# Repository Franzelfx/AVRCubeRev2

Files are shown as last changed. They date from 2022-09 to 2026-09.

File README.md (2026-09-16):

# AVR-Cube (Rev2)

**A coin-cell powered electronic dice and two-axis spirit level on an ATtiny24 — seven LEDs, one button, one accelerometer, and a bit-banged I²C bus that shares its pins with the ISP header.**

Shake it and it rolls a number; press the button and the same seven LEDs become a bubble level that follows the tilt of the board. It sleeps after a minute of stillness and wakes on the button, so a CR2032 lasts a long time. Designed as an easy, satisfying through-hole soldering kit: 25 parts, all on one side.

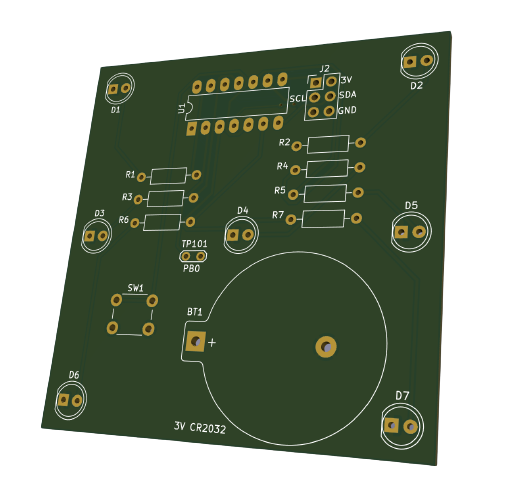
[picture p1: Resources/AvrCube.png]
AVR-Cube Rev2 board render


https://user-images.githubusercontent.com/38862049/217531555-265ecb9a-27d7-4d04-bca4-034f5620d8f7.mov

---

## Contents

- [How it works](#how-it-works)
- [Hardware](#hardware)
- [Firmware](#firmware)
- [Building and flashing](#building-and-flashing)
- [Repository layout](#repository-layout)
- [Status and known limitations](#status-and-known-limitations)
- [Author](#author)
- [License](#license)

---

## How it works

The whole device is one state machine driven by two interrupts: a 1 ms timer tick that counts idle time, and the button on `INT0`.

```mermaid
stateDiagram-v2
    [*] --> Calibrate : battery inserted / wake from sleep
    Calibrate --> SpiritLevel : all LEDs → "1" → sensor check ✓ → "2" → offset averaged → ✓
    Calibrate --> Sleep : sensor not answering (✗ shown for 60 s)

    SpiritLevel --> Dice : button
    Dice --> SpiritLevel : button

    state Dice {
        [*] --> Waiting
        Waiting --> Rolling : tilt changes by > 25°
        Rolling --> Waiting : 5 fast + 5 slowing steps, last number stays lit
    }

    SpiritLevel --> Sleep : 60 s without motion
    Dice --> Sleep : 60 s without motion
    SpiritLevel --> Sleep : button held 3 s
    Dice --> Sleep : button held 3 s
    Sleep --> Calibrate : button
```

**Calibration** runs on every wake-up: it lights all LEDs (a visual LED test), reads the accelerometer's `WHO_AM_I` register over I²C, and averages ten samples to get the resting offset on each axis. That offset is what makes the spirit level read "flat" wherever the board happens to sit when powered on — there is no absolute calibration.

**Spirit level** reads X/Y/Z acceleration, subtracts the offset, and converts the X and Y components into roll and pitch angles with `atan(axis / z_offset)`. Within ±1° of level only the centre LED is lit; otherwise the LEDs on the side that is *down* light up — a whole edge if the tilt is along one axis, a single corner if it's diagonal.

**Dice** waits until the angle changes by more than 25° between two readings (a shake or a tilt), then rolls: five numbers at 100 ms, then five more with the delay growing by 100 ms each step, so the animation visibly slows down and settles. The random generator is seeded from the millisecond counter, so the result depends on exactly when you shook it.

**Sleep** puts the accelerometer in standby, switches every I/O pin to input, and enters `SLEEP_MODE_PWR_DOWN` — a few µA. Holding the button lights the LEDs 1…6 as a countdown; at 3 s it sleeps immediately.

## Hardware

| | |
|---|---|
| MCU | Microchip **ATtiny24** (DIP-14, 2 KB flash) at 8 MHz internal RC — the ATtiny84 is a drop-in alternative with more flash |
| Sensor | NXP **MMA8653FC** 3-axis accelerometer (DFN-10), I²C address `0x1D`, ±2 g, 8-bit fast-read mode |
| Display | 7 × 5 mm LEDs in the classic dice pattern, 100 Ω series resistors |
| Input | 6 mm tactile switch on `INT0` |
| Power | CR2032 in a Keystone 106 holder, 3 V direct — no regulator |
| Programming | 2×3 ISP header; the same pins carry the sensor's I²C bus |
| Board | 2-layer, single-sided assembly, KiCad 6 sources in [PCB/](PCB/), Gerbers in [PCB/Gerber/Rev26.09.22/](PCB/Gerber/Rev26.09.22/) |

### LED layout and pin map

```
        D1 ●     ● D2            D1  PA0     D5  PA5 (also MISO)
                                 D2  PA1     D6  PA7
        D3 ●  ●  ● D5            D3  PA2     D7  PB1
              D4                 D4  PA3

        D6 ●     ● D7            SW1  PB2 / INT0   (pull-up, active low)
                                 SCL  PA4 = SCK    (bit-banged, no USI)
   1 → D4   2 → D3 D5            SDA  PA6 = MOSI
   3 → D1 D4 D7   4 → corners    TP101 PB0 (spare, pulled up)
   5 → corners + D4   6 → all but D4
```

Sharing `SCK`/`MOSI` with `SCL`/`SDA` is what keeps the part count down: no dedicated I²C header, and the sensor doesn't mind the ISP traffic because the firmware drives the bus in software and the sensor ignores anything without a valid start condition addressed to it. `D5` sits on `MISO` and flickers while programming — harmless.

### Bill of materials

| Ref | Qty | Part | Footprint |
|---|:---:|---|---|
| U1 | 1 | ATtiny24-20PU (or ATtiny84) | DIP-14 |
| U2 | 1 | MMA8653FCR1 | DFN-10 2×2 mm — the only SMD part |
| D1–D7 | 7 | LED 5 mm | THT |
| R1–R7 | 7 | 100 Ω | axial 0207 |
| C1–C3 | 3 | 100 nF | 0603 |
| C4–C5 | 2 | 1 µF | 0603 |
| SW1 | 1 | tactile switch 6 mm | THT |
| BT1 | 1 | CR2032 holder, Keystone 106 | THT |
| J2 | 1 | pin header 2×3, 2.54 mm | THT |

The schematic ([PCB/avrCubeRev2.kicad_sch](PCB/avrCubeRev2.kicad_sch)) is the authoritative BOM; datasheets for every active part are in [Documentation/](Documentation/).

## Firmware

Everything lives in [AvrCubeV2Code/src/main.cpp](AvrCubeV2Code/src/main.cpp) and [main.hpp](AvrCubeV2Code/src/main.hpp) — bare-metal AVR C++ with no Arduino API calls, built with the PlatformIO `atmelavr` toolchain. Doxygen comments on every function; the generated reference is in [Documentation/Doxygen/documentation.pdf](Documentation/Doxygen/documentation.pdf).

Things worth knowing before you change it:

- **I²C is bit-banged** (`start()`, `stop()`, `tx()`, `rx()`) at ~100 kHz using the internal pull-ups — the ATtiny24's USI is not used so the pins can double as ISP. Interrupts are disabled during each register transaction.
- **The 1 ms tick** is Timer0 in CTC mode (prescaler 64, `OCR0A = 124` at 8 MHz). It only increments `counter`; `main()` compares it against `SLEEP_THRESHOLD` and any detected motion resets it.
- **Mode switching** is done by parity of `button_pressed`: the ISR increments it and re-enters `main()`, which re-initialises the peripherals and picks the branch. Odd = dice, even = spirit level; calibration leaves it at 2, so the device starts in level mode.
- **All tunables are `#define`s** at the top of `main.hpp`: sleep timeout, shake threshold, dice animation timing, level dead-band, hold-to-sleep time.

## Building and flashing

Requirements: [PlatformIO](https://platformio.org/) (CLI or VS Code extension) and an ISP programmer — an Arduino running *ArduinoISP* works, that's what `flashCommand.txt` assumes.

```bash
cd AvrCubeV2Code
pio run -e attiny24            # or -e attiny84
```

Flash with avrdude, setting the fuses for the internal 8 MHz oscillator with `CKDIV8` cleared (`lfuse 0xE2`); the default `hfuse 0xDF` keeps `RESET` usable so the chip stays re-programmable:

```bash
avrdude -p t24 -c avrisp -b 19200 -P /dev/ttyUSB0 \
  -U flash:w:.pio/build/attiny24/firmware.hex \
  -U lfuse:w:0xe2:m -U hfuse:w:0xdf:m -U efuse:w:0xff:m
```

Insert the coin cell after programming. The board should light all seven LEDs, show `1`, then a tick mark (✓) if the accelerometer answered, show `2` while it averages the offset, and a tick again — then it's in spirit-level mode. A cross (✗) after `1` means the I²C link to the sensor is broken; check the DFN-10 solder joints.

## Repository layout

```
AvrCubeV2Code/         PlatformIO project
  src/main.cpp, main.hpp   the whole firmware
  platformio.ini           attiny24 and attiny84 environments
  flashCommand.txt         avrdude invocation with fuse settings
  Doxygen/Doxyfile         doc generator config
PCB/                   KiCad 6 project (schematic, layout, footprint table)
  Gerber/Rev26.09.22/      latest production files (also Rev09.22, Rev1.0)
Documentation/         datasheets (ATtiny24, MMA8653FC, LED) and the Doxygen PDF
Resources/             board render, demo video, KiCad battery-holder footprints
```

## Status and known limitations

The Rev2 board is built, tested and works as shown in the video. Things left open in the firmware:

- **Angle maths is an approximation.** Roll and pitch use `atan(x / z_offset)` with the *calibrated* Z as the fixed reference rather than `atan2(x, sqrt(y²+z²))`. It's accurate near level and increasingly off beyond ~45°, which is fine for a bubble level but not for measuring angles. The NXP app note AN3461 has the exact formulas; the code comment already points at it.
- **Motion detection is rough.** `motionDetected()` compares the angle *gradient* to the threshold without `abs()`, so only changes in the positive direction trigger — and `getGradient()` keeps a single static previous value shared between the roll and pitch calls, so each "gradient" is really roll-minus-pitch of consecutive reads. Shaking still trips it reliably, which is all the dice needs, but it should be two independent deltas with `abs()`.
- **Offset lives in RAM.** Calibration repeats on every wake-up rather than storing the offset in the sensor's own offset registers (`OFF_X/Y/Z`), which the MMA8653FC supports.
- **Mode switching re-enters `main()` from the ISR**, which is a stack-growing trick rather than a clean state variable. It works because the device sleeps or is power-cycled long before the stack matters, but it's the first thing to refactor.
- **Flash is tight on the ATtiny24.** Float `atan` plus `rand` fits, but there is little room left; the ATtiny84 environment exists for that reason.

## Author

Fabian Franz, 2022.

## License

Firmware, schematic and board layout: [MIT](LICENSE). Datasheets in `Documentation/` belong to their respective manufacturers.

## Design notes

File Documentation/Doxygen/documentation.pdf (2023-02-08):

## AVRCubeRev2

Generated by Doxygen 1.9.5

i

1 File Index | 1
2 File Documentation | 3

2.1 /Users/FabianFranz/Development/Projects/AVRCubeRev2/AvrCubeV2Code/src/main.hpp File Refer-

Index | 13

Generated by Doxygen

# Chapter 1

# File Index

## 1.1 File List

Here is a list of all documented files with brief descriptions:

/Users/FabianFranz/Development/Projects/AVRCubeRev2/AvrCubeV2Code/src/main.hpp

### 2 File Index

# Chapter 2

# File Documentation

## 2.1 /Users/FabianFranz/Development/Projects/AVRCubeRev2/AvrCube←-V2Code/src/main.hpp File Reference

Implementation of functionality for the "Cube Project".

#include <math.h>

#include <stdlib.h>

#include <avr/io.h>

#include <avr/sleep.h>

#include <util/delay.h>

#include <avr/interrupt.h>

Macros

- #define F_CPU 8000000
- #define __DELAY_BACKWARD_COMPATIBLE__
- #define BUTTON PB2
- #define D1 PA0
- #define D2 PA1
- #define D3 PA2
- #define D4 PA3
- #define D5 PA5
- #define D6 PA7
- #define D7 PB1
- #define SCK PA4
- #define MISO PA5
- #define MOSI PA6
- #define SCL PA4
- #define SDA PA6
- #define UNCONNECTED PB0
- #define OUTPUT 0
- #define INPUT 1
- #define ENABLE true
- #define DISABLE false

### 4 File Documentation

- #define ON true
- #define OFF false
- #define SLEEP_THRESHOLD 60000
- #define ACCELERATION_THRESHOLD 100
- #define DICE_STEPS_FIRST_ROUND 5
- #define DICE_STEPS_SECOND_ROUND 5
- #define DICE_TIME_STEPS 100
- #define DICE_TIME_STEPS_INCREASE 10
- #define ANGLETHRESHOLD 5
- #define CALIBRATION_STEP_DELAY 500
- #define OFFSET_CALIBRATION_STEPS 10
- #define OFFSET_CALIBRATION_STEP_DELAY 10
- #define FORCE_SLEEP_STEPTIME 500
- #define FORCE_SLEEP_TIME 6 ∗ FORCE_SLEEP_STEPTIME
- #define I2C_DELAY 10
- #define SDA_ON (PORTA |= (1 << SDA))
- #define SDA_OFF (PORTA &= ∼(1 << SDA))
- #define SCL_READ (PINA & (1 << SCL))
- #define SDA_READ (PINA & (1 << SDA))
- #define MMA8653FC_ADD 0x1D
- #define MMA8653FC_ADDR_READ 0x3B
- #define MMA8653FC_ADDR_WRITE 0x3A
- #define MMA8653FC_WHO_AM_I 0x0D
- #define MMA8653FC_XYZ_DATA_CFG 0x0E
- #define MMA8653FC_CTRL_REG1 0x2A
- #define MMA8653FC_SYSMOD 0x0B
- #define MMA8653FC_OUT_X_MSB 0x01
- #define MMA8653FC_OUT_X_LSB 0x02
- #define MMA8653FC_OUT_Y_MSB 0x03
- #define MMA8653FC_OUT_Y_LSB 0x04
- #define MMA8653FC_OUT_Z_MSB 0x05
- #define MMA8653FC_OUT_Z_LSB 0x06

Functions

- void setLedPins (uint8_t mode)

Set the LED Pins eigther "INPUT" or "OUTPUT".
- void setSDA (bool mode)

Set the SDA pin eighter "ON" or "OFF".
- void setSCL (bool mode)

Set the SCL pin eighter "ON" or "OFF".
- void init ()

Initialises all the AVR hardware E.g. ports, interrupts, timers, etc.
- void allLedOn ()

Turn on all LEDs (LED1 - LED7)
- void allLedOff ()

Turn off all LEDs (LED1 - LED7)
- void deInit ()

Deeinitialises all the AVR hardware E.g. ports, interrupts, timers, etc.
- void showNumber (uint8_t numberToShow)

Show a number between 1 and 6 on the LEDs.
- void showCross ()

2.1 /Users/FabianFranz/Development/Projects/AVRCubeRev2/AvrCubeV2Code/src/main.hpp File Reference5

Show a cross on the LEDs.
- void showHook ()

Show a hook on the LEDs.
- void testLeds ()

Check if all LEDs are working correctly.
- void start ()

I2C BitBang start condition.
- void stop ()

I2C BitBang stop condition.
- bool tx (uint8_t dat)

I2C BitBang tx of one byte.
- uint8_t rx (bool ack)

I2C BitBang rx of one byte.
- uint8_t readRegister (uint8_t reg)

Read a register from the MMA8653FC.
- void writeRegister (uint8_t reg, uint8_t value)

Write a value to a register of the MMA8653FC.
- void testI2C_read ()

Checks, if the I2C connection to the MMA8653FC is working.

### 2.1.1 Detailed Description

Implementation of functionality for the "Cube Project".

Function includes, defines and function prototypes for main.cpp.

Author

Fabian Franz fabian.franz0596@gmail.com

Version

09.22

Date

2022-09-14

Copyright

Copyright (c) 2022

______ | _ | _ | _
| | ____| | /\ | | | | | | | | |
| |__ | / | \ | | |__| | | ______ | | | ___ _ __ | __ _
| | __| | / /\ \ | | __ | | |______| | _ | | |/ _ \ ’_ \ / _‘ |
| |____ / ____ \| | | | | | | |__| | | __/ | | | (_| |
|______/_/ | \_\_| | |_| | \____/ \___|_| |_|\__,_|

### 2.1.2 Function Documentation

### 6 File Documentation

### 2.1.2.1 deInit()

void deInit ( )

Deeinitialises all the AVR hardware E.g. ports, interrupts, timers, etc.

Remarks

Calling deInit(); is necessary to save power before the CPU goes to sleep.

### 2.1.2.2 readRegister()

uint8_t readRegister (

uint8_t reg )

Read a register from the MMA8653FC.

Parameters

reg The register to read.

Returns

The value of the register.

### 2.1.2.3 rx()

uint8_t rx (

bool ack )

I2C BitBang rx of one byte.

Parameters

ack ACK or NACK (acknowledge or no acknowledge)

Returns

The received byte.

2.1 /Users/FabianFranz/Development/Projects/AVRCubeRev2/AvrCubeV2Code/src/main.hpp File Reference7

### 2.1.2.4 setLedPins()

void setLedPins (

uint8_t mode )

Set the LED Pins eigther "INPUT" or "OUTPUT".

Parameters

mode OUTPUT = 0 or INPUT = 1

### 2.1.2.5 setSCL()

void setSCL (

bool mode )

Set the SCL pin eighter "ON" or "OFF".

Parameters

mode "ON" (input pullup) or "OFF" (output low)

### 2.1.2.6 setSDA()

void setSDA (

bool mode )

Set the SDA pin eighter "ON" or "OFF".

Parameters

mode "ON" (input pullup) or "OFF" (output low)

### 2.1.2.7 showCross()

void showCross ( )

Show a cross on the LEDs.

Remarks

This function is used to indicate some error.

### 8 File Documentation

### 2.1.2.8 showHook()

void showHook ( )

Show a hook on the LEDs.

Remarks

This function is used to indicate some success.

### 2.1.2.9 showNumber()

void showNumber (

uint8_t numberToShow )

Show a number between 1 and 6 on the LEDs.

Parameters

numberToshow The number to show on the LEDs.

Lremark If the number is larger than 6, no LED will be turned on.

### 2.1.2.10 start()

void start ( )

I2C BitBang start condition.

### 2.1.2.11 stop()

void stop ( )

I2C BitBang stop condition.

### 2.1.2.12 testI2C_read()

void testI2C_read ( )

Checks, if the I2C connection to the MMA8653FC is working.

Remarks

If the communication is not working, it will be shown on the LEDs as a cross. Furthermore, the device will go to sleep.

2.2 main.hpp | 9

### 2.1.2.13 testLeds()

void testLeds ( )

Check if all LEDs are working correctly.

### 2.1.2.14 tx()

bool tx (

uint8_t dat )

I2C BitBang tx of one byte.

Parameters

dat The byte to send.

Returns

ACK or NACK (acknowledge or no acknowledge)

### 2.1.2.15 writeRegister()

void writeRegister (

uint8_t reg,

uint8_t value )

Write a value to a register of the MMA8653FC.

Parameters

reg | The register to write.
value | The value to write.

## 2.2 main.hpp

Go to the documentation of this file.

1
21 #ifndef MAIN_HPP
22 #define MAIN_HPP
23
24 // ---------------------------------------------------------------- // 25 // -- Includes ---------------------------------------------------- // 26 // ---------------------------------------------------------------- // 27 #include <math.h>
28 #include <stdlib.h>

### 10 File Documentation

29 #include <avr/io.h>
30 #include <avr/sleep.h>
31 #include <util/delay.h>
32 #include <avr/interrupt.h>
33
34 // ---------------------------------------------------------------- // 35 // -- Defines ----------------------------------------------------- // 36 // ---------------------------------------------------------------- // 37 #define F_CPU 8000000
38 #define __DELAY_BACKWARD_COMPATIBLE__
39 // Defines for the button pin
40 #define BUTTON PB2
41 // Defines for the connected LEDs
42 #define D1 PA0
43 #define D2 PA1
44 #define D3 PA2
45 #define D4 PA3
46 #define D5 PA5
47 #define D6 PA7
48 #define D7 PB1
49 // Defines for the SPI interface. 50 #define SCK PA4
51 #define MISO PA5
52 #define MOSI PA6
53 // Defines for the I2C interface (no hardware interface). 54 #define SCL PA4
55 #define SDA PA6
56 // Defines for unconnected pins
57 #define UNCONNECTED PB0
58
59 // General defines
60 #define OUTPUT 0
61 #define INPUT 1
62 #define ENABLE true
63 #define DISABLE false
64 #define ON true
65 #define OFF false
66
67 // Defines for control flow
68 #define SLEEP_THRESHOLD 60000 | // Millieconds until the device go to sleep if no action occurs
69 #define ACCELERATION_THRESHOLD 100 | // The threshold for the absolute motion value in LSB registers
70 #define DICE_STEPS_FIRST_ROUND 5 | // The number of steps the dice has to roll
71 #define DICE_STEPS_SECOND_ROUND 5 | // The number of steps the dice has to roll
72 #define DICE_TIME_STEPS 100 | // The time step between dice rolls in ms
73 #define DICE_TIME_STEPS_INCREASE 10 // The time step increase between dice rolls in ms in secon round
74 #define ANGLETHRESHOLD 5 | // The threshold for the angle in degrees
75 #define CALIBRATION_STEP_DELAY 500 | // The delay between calibration steps in ms
76 #define OFFSET_CALIBRATION_STEPS 10 | // The number of calibration steps
77 #define OFFSET_CALIBRATION_STEP_DELAY 10 // The delay between offset calibration steps in ms
78 #define FORCE_SLEEP_STEPTIME 500 | // The delay until new number
79 #define FORCE_SLEEP_TIME 6 * FORCE_SLEEP_STEPTIME // When button is hold this amout of milliseconds the device will go to sleep
80
81 // Defines for I2C
82 #define I2C_DELAY 10 // 10 us -> 100 kHz 83 #define SDA_ON (PORTA |= (1 « SDA))
84 #define SDA_OFF (PORTA &= ~(1 « SDA)) 85 #define SCL_READ (PINA & (1 « SCL))
86 #define SDA_READ (PINA & (1 « SDA)) 87 // Defines for Acceleration Sensor 88 #define MMA8653FC_ADD 0x1D
89 #define MMA8653FC_ADDR_READ 0x3B
90 #define MMA8653FC_ADDR_WRITE 0x3A
91 // Defines for Acceleration Sensor Registers 92 #define MMA8653FC_WHO_AM_I 0x0D
93 #define MMA8653FC_XYZ_DATA_CFG 0x0E
94 #define MMA8653FC_CTRL_REG1 0x2A
95 #define MMA8653FC_SYSMOD 0x0B | // System Mode, to control STANDBY, WAKE and SLEEP
96 #define MMA8653FC_OUT_X_MSB 0x01 // Most significant byte of X-axis acceleration data 97 #define MMA8653FC_OUT_X_LSB 0x02 // Least significant byte of X-axis acceleration data 98 #define MMA8653FC_OUT_Y_MSB 0x03 // Most significant byte of Y-axis acceleration data 99 #define MMA8653FC_OUT_Y_LSB 0x04 // Least significant byte of Y-axis acceleration data 100 #define MMA8653FC_OUT_Z_MSB 0x05 // Most significant byte of Z-axis acceleration data 101 #define MMA8653FC_OUT_Z_LSB 0x06 // Least significant byte of Z-axis acceleration data 102
103 // ---------------------------------------------------------------- //
104 // -- Function Prototypes ----------------------------------------- //
105 // ---------------------------------------------------------------- // 111 void setLedPins(uint8_t mode);
117 void setSDA(bool mode);
123 void setSCL(bool mode);
127 void init();
132 void allLedOn();
136 void allLedOff();
142 void deInit();
150 void showNumber(uint8_t numberToShow); 156 void showCross();

2.2 main.hpp | 11

162 void showHook();
167 void testLeds();
172 void start();
177 void stop();
185 bool tx(uint8_t dat);
193 uint8_t rx(bool ack);
201 uint8_t readRegister(uint8_t reg);
208 void writeRegister(uint8_t reg, uint8_t value); 209
217 void testI2C_read();
218
219 #endif /* MAIN_HPP */

### 12 File Documentation

# Index

/Users/FabianFranz/Development/Projects/AVRCubeRev2/AvrCubeV2Code/src/main.hpp, 3, 9

deInit
main.hpp, 5

main.hpp
deInit, 5
readRegister, 6
rx, 6
setLedPins, 6
setSCL, 7
setSDA, 7
showCross, 7
showHook, 7
showNumber, 8
start, 8
stop, 8
testI2C_read, 8
testLeds, 8
tx, 9
writeRegister, 9

readRegister
main.hpp, 6
rx
main.hpp, 6

setLedPins
main.hpp, 6
setSCL
main.hpp, 7
setSDA
main.hpp, 7
showCross
main.hpp, 7
showHook
main.hpp, 7
showNumber
main.hpp, 8
start
main.hpp, 8
stop
main.hpp, 8

testI2C_read
main.hpp, 8
testLeds
main.hpp, 8
tx
main.hpp, 9

writeRegister
main.hpp, 9

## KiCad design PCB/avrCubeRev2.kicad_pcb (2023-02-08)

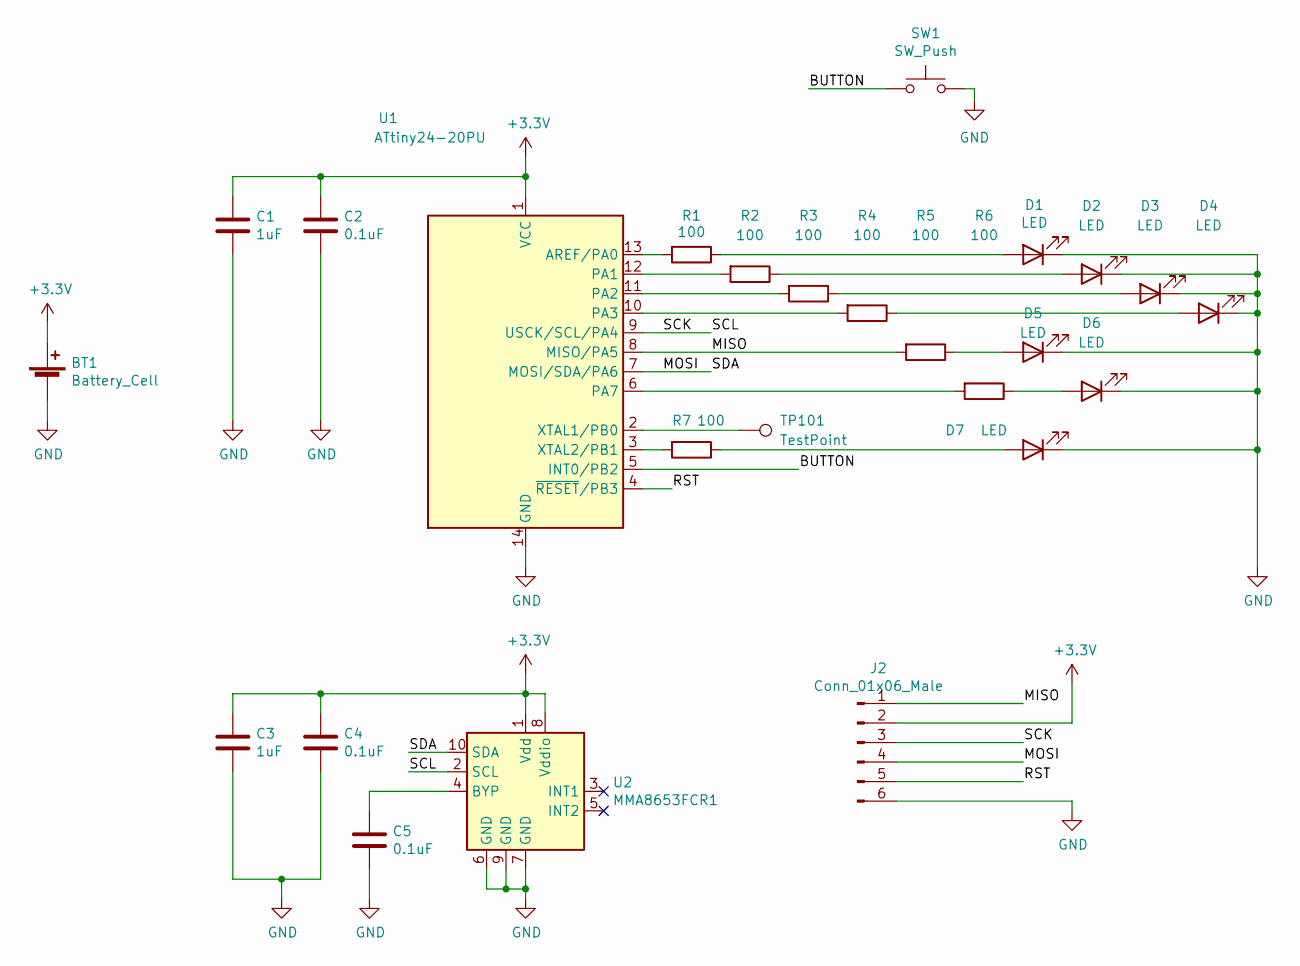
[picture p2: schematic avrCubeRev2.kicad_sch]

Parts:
BT1: Battery_Cell; BatteryHolder_Keystone_106_1x20mm
C1, C3: 1uF; C_0603
C2, C4, C5: 0.1uF; C_0603
D1, D2, D3, D4, D5, D6, D7: LED; LED_D5.0mm
J2: Conn_01x06_Male; Pin_Header_Straight_2x03_Pitch2.54mm
R1, R2, R3, R4, R5, R6, R7: 100; R_Axial_DIN0207_L6.3mm_D2.5mm_P10.16mm_Horizontal
SW1: SW_Push; SW_PUSH_6mm_h4.3mm
TP101: TestPoint; TestPoint_2Pads_Pitch2.54mm_Drill0.8mm
U1: ATtiny24-20PU; DIP-14_W7.62mm_LongPads
U2: MMA8653FCR1; DFN-10_2x2mm_Pitch0.4mm

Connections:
+3V3: BT1.1 (+), C1.1, C2.1, C3.1, C4.1, J2.2, U1.1 (VCC), U2.1 (Vdd), U2.8 (Vddio)
/BUTTON: SW1.1, U1.5 (INT0/PB2)
/MISO: J2.1, R5.2, U1.8 (MISO/PA5)
/MOSI: J2.4, U1.7 (MOSI/SDA/PA6), U2.10 (SDA)
/RST: J2.5, U1.4 (~RESET/PB3)
/SCK: J2.3, U1.9 (USCK/SCL/PA4), U2.2 (SCL)
GND: BT1.2 (-), C1.2, C2.2, C3.2, C4.2, C5.2, D1.1 (K), D2.1 (K), D3.1 (K), D4.1 (K), D5.1 (K), D6.1 (K), D7.1 (K), J2.6, SW1.2, TP101.2, U1.14 (GND), U2.6 (GND), U2.7 (GND), U2.9 (GND)
unnamed: C5.1, U2.4 (BYP)
unnamed: D1.2 (A), R1.1
unnamed: D2.2 (A), R2.1
unnamed: D3.2 (A), R3.1
unnamed: D4.2 (A), R4.1
unnamed: D5.2 (A), R5.1
unnamed: D6.2 (A), R6.1
unnamed: D7.2 (A), R7.1
unnamed: R1.2, U1.13 (AREF/PA0)
unnamed: R2.2, U1.12 (PA1)
unnamed: R3.2, U1.11 (PA2)
unnamed: R4.2, U1.10 (PA3)
unnamed: R6.2, U1.6 (PA7)
unnamed: R7.2, U1.3 (XTAL2/PB1)
unnamed: TP101.1, U1.2 (XTAL1/PB0)

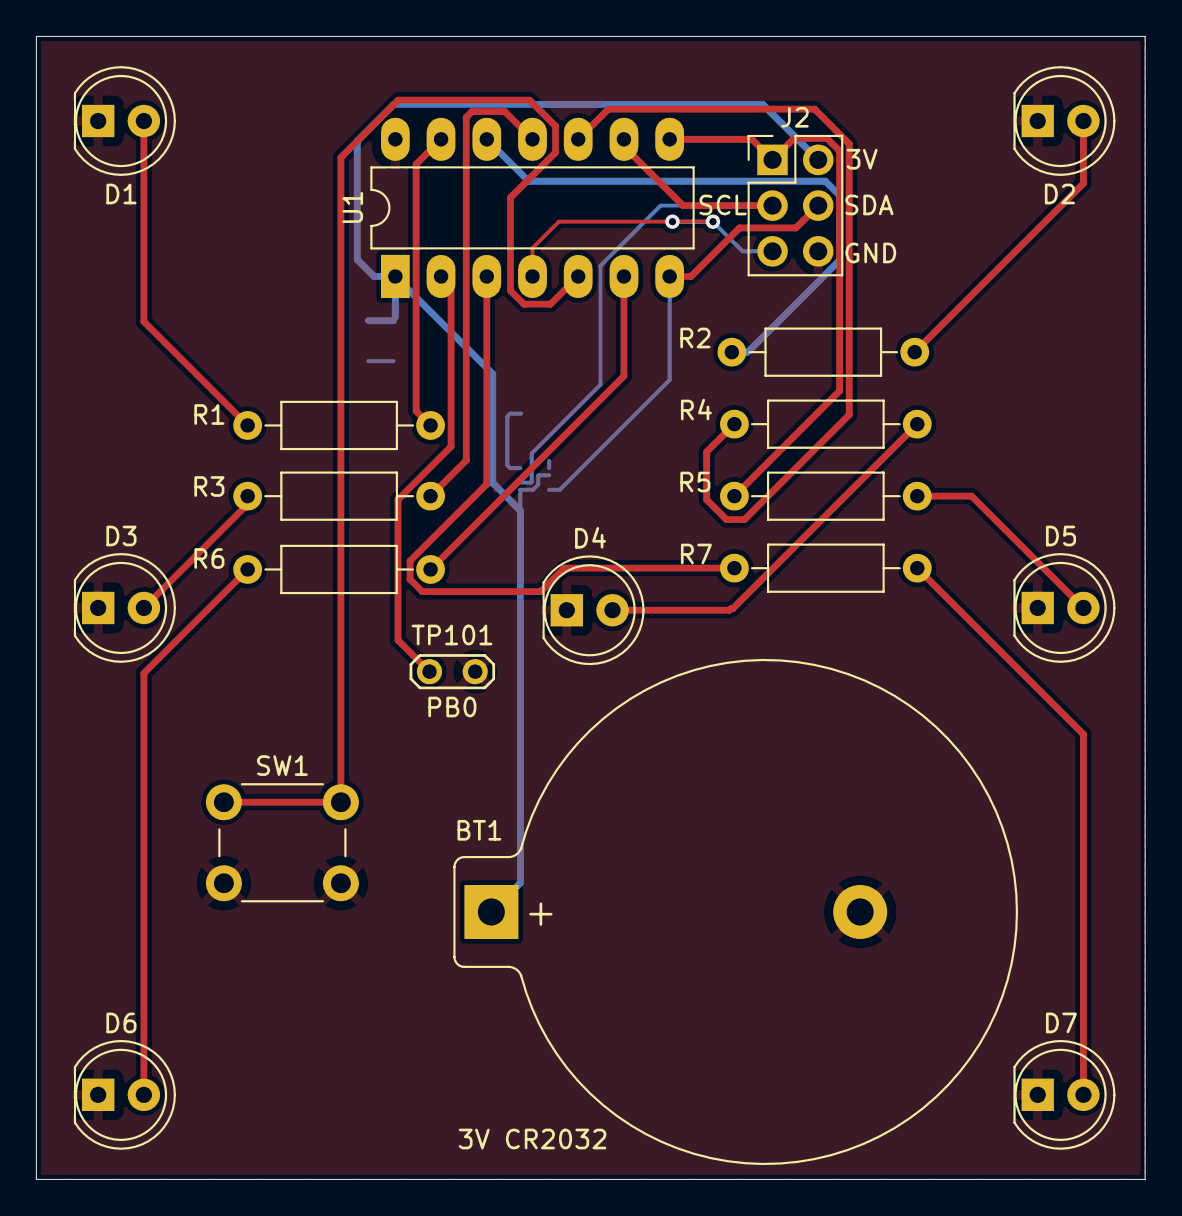
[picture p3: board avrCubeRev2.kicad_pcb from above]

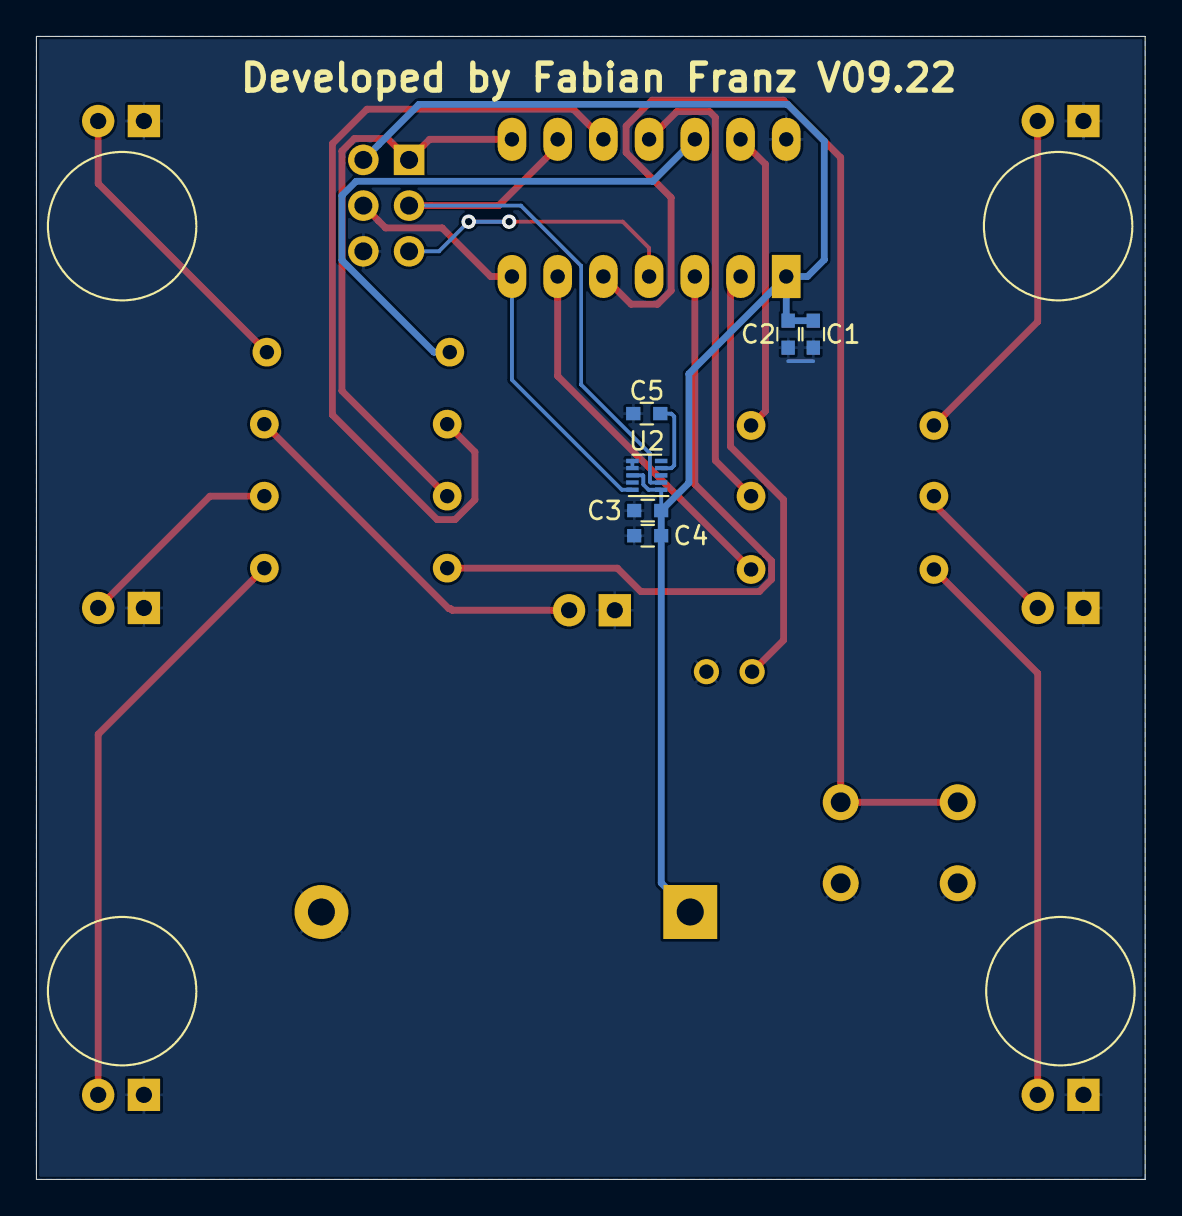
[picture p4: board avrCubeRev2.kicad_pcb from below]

Board: 2 copper layers, 61.6 x 63.5 mm, 25 parts (6 on the bottom side), 22 nets.

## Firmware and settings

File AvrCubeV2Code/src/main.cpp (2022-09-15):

/**
 * @file main.cpp
 * @author Fabian Franz fabian.franz0596@gmail.com
 * @brief Implementation of functionality for the "Cube Project".
 * @version 09.22
 * @date 2022-09-14
 *
 * @copyright Copyright (c) 2022
 *
 * \code
  ______          _    _                 _
 |  ____|   /\   | |  | |               | |
 | |__     /  \  | |__| |  ______       | | ___ _ __   __ _
 |  __|   / /\ \ |  __  | |______|  _   | |/ _ \ '_ \ / _` |
 | |____ / ____ \| |  | |          | |__| |  __/ | | | (_| |
 |______/_/    \_\_|  |_|           \____/ \___|_| |_|\__,_|

 * \endcode
 */

#include "main.hpp"

 // Global variable for interrupt.
volatile uint16_t counter = 0;        // Counter for the sleep timer. -> max = 65.535
volatile uint8_t button_pressed = 0;  // Counter for button pressed, to decide if even or odd.
int16_t x_offset, y_offset, z_offset; // Global variables for sensor offset.
// #TODO write offset value in sensor registers

// ---------------------------------------------------------------- //
// -- Local functions --------------------------------------------- //
// ---------------------------------------------------------------- //
void setLedPins(uint8_t mode)
{
  if (mode == OUTPUT) {
    DDRA |= (1 << D1) | (1 << D2) | (1 << D3) | (1 << D4) | (1 << D5) | (1 << D6);
    DDRB |= (1 << D7);
  }
  else if (mode == INPUT)
  {
    DDRA &= ~(1 << D1) & ~(1 << D2) & ~(1 << D3) & ~(1 << D4) & ~(1 << D5) & ~(1 << D6);
    DDRB &= ~(1 << D7);
  }
}
void setSDA(bool mode) {
  // If SDA has to be set "on", internal pullup resistor will be enabled
  if (mode == ON) {
    DDRA &= ~(1 << SDA);
    PORTA |= (1 << SDA);
  }
  // If SDA has to be set "off", pin will be driven low
  else if (mode == OFF) {
    DDRA |= (1 << SDA);
    PORTA &= ~(1 << SDA);
  }
}
void setSCL(bool mode) {
  // If SCL has to be set "on", internal pullup resistor will be enabled
  if (mode == ON) {
    DDRA &= ~(1 << SCL);
    PORTA |= (1 << SCL);
  }
  // If SCL has to be set "off", pin will be driven low
  else {
    DDRA |= (1 << SCL);
    PORTA &= ~(1 << SCL);
  }
}
void init() {
  // Setup the LED and I2C pins as outputs.
  setLedPins(OUTPUT);
  // Setup the timer to check for inactivity.
  TIMSK0 |= (1 << OCIE0A);
  TCCR0A |= (1 << WGM01);              // CTC mode
  TCCR0B |= (1 << CS00) | (1 << CS01); // Prescaler 64
  OCR0A |= 124;                        // Resulting in ca. 1ms interrupt.
  // Setup external interrupt INT0.
  DDRB &= ~(1 << BUTTON);               // Set the button pin as input.
  PORTB |= (1 << BUTTON);               // Enable pull-up resistor.
  GIMSK |= (1 << INT0);                 // Enable INT0.
  // Set unconnected pin to input pullup
  DDRB &= ~(1 << UNCONNECTED);
  PORTB |= (1 << UNCONNECTED);
  // Enable interrupts
  sei();
}
void allLedOn()
{
  PORTA |= (1 << D1) | (1 << D2) | (1 << D3) | (1 << D4) | (1 << D5) | (1 << D6);
  PORTB |= (1 << D7);
}
void allLedOff()
{
  PORTA &= ~(1 << D1) & ~(1 << D2) & ~(1 << D3) & ~(1 << D4) & ~(1 << D5) & ~(1 << D6);
  PORTB &= ~(1 << D7);
}
void deInit() {
  button_pressed = 0;
  allLedOff();
  setLedPins(INPUT);
  setSDA(INPUT);
  setSCL(INPUT);
  sei();
}
void showNumber(uint8_t numberToShow)
{
  allLedOff();
  switch (numberToShow)
  {
  case 1:
    PORTA |= (1 << D4);
    break;
  case 2:
    PORTA |= (1 << D3);
    PORTA |= (1 << D5);
    break;
  case 3:
    PORTA |= (1 << D1);
    PORTA |= (1 << D4);
    PORTB |= (1 << D7);
    break;
  case 4:
    PORTA |= (1 << D1);
    PORTA |= (1 << D2);
    PORTA |= (1 << D6);
    PORTB |= (1 << D7);
    break;
  case 5:
    PORTA |= (1 << D1);
    PORTA |= (1 << D2);
    PORTA |= (1 << D4);
    PORTA |= (1 << D6);
    PORTB |= (1 << D7);
    break;
  case 6:
    PORTA |= (1 << D1);
    PORTA |= (1 << D2);
    PORTA |= (1 << D3);
    PORTA |= (1 << D5);
    PORTA |= (1 << D6);
    PORTB |= (1 << D7);
    break;
  default:
    break;
  }
}
void showCross() {
  allLedOff();
  PORTA |= (1 << D1);
  PORTA |= (1 << D2);
  PORTA |= (1 << D4);
  PORTA |= (1 << D6);
  PORTB |= (1 << D7);
}
void showHook() {
  allLedOff();
  PORTA |= (1 << D2);
  PORTA |= (1 << D3);
  PORTA |= (1 << D4);
  PORTA |= (1 << D6);
}
void testLeds() {
  for (uint8_t i = 1; i <= 6; i++)
  {
    showNumber(i);
    _delay_ms(1000);
  }
}
// I2C BitBang Functions
void start() {
  setSDA(ON);  // Set SDA high.
  _delay_us(I2C_DELAY);
  setSCL(ON);  // Set SCL high.
  _delay_us(I2C_DELAY);
  setSDA(OFF); // Set SDA low, start condition is achieved.
  _delay_us(I2C_DELAY);
  setSCL(OFF); // Set SCL low.
  _delay_us(I2C_DELAY);
}
void stop() {
  setSDA(OFF); // Set SDA low, stop condition is achieved.
  _delay_us(I2C_DELAY);
  setSCL(ON);  // Set SCL high.
  _delay_us(I2C_DELAY);
  setSDA(ON);  // Set SDA high.
  _delay_us(I2C_DELAY);
}
bool tx(uint8_t dat) {

  for (uint8_t i = 8; i; i--) {
    (dat & 0x80) ? setSDA(ON) : setSDA(OFF); //Mask for the eigth bit
    _delay_us(I2C_DELAY);
    setSCL(ON);
    _delay_us(I2C_DELAY);
    setSCL(OFF);
    _delay_us(I2C_DELAY);
    dat <<= 1;  //Move 
  }
  setSDA(ON);
  _delay_us(I2C_DELAY);
  setSCL(ON);
  _delay_us(I2C_DELAY);
  bool ack = !SDA_READ;    // Acknowledge bit
  setSCL(OFF);
  return ack;
}
uint8_t rx(bool ack) {
  uint8_t dat = 0;
  setSDA(ON);
  for (uint8_t i = 0; i < 8; i++) {
    dat <<= 1;
    do {
      setSCL(ON);
    } while (SCL_READ == 0);  //clock stretching
    _delay_us(I2C_DELAY);
    if (SDA_READ) dat |= 1;
    _delay_us(I2C_DELAY);
    setSCL(OFF);
  }
  ack ? SDA_OFF : SDA_ON;
  setSCL(ON);
  _delay_us(I2C_DELAY);
  setSCL(OFF);
  setSDA(ON);
  return(dat);
}
uint8_t readRegister(uint8_t reg) {
  cli();
  start();
  tx(MMA8653FC_ADDR_WRITE);
  _delay_us(5 * I2C_DELAY);
  tx(reg);
  _delay_us(5 * I2C_DELAY);
  start();
  _delay_us(5 * I2C_DELAY);
  tx(MMA8653FC_ADDR_READ);
  _delay_us(5 * I2C_DELAY);
  uint8_t value = rx(false);
  stop();
  sei();
  _delay_us(5 * I2C_DELAY);
  return value;
}
void writeRegister(uint8_t reg, uint8_t value) {
  cli();
  start();
  tx(MMA8653FC_ADDR_WRITE);
  _delay_us(5 * I2C_DELAY);
  tx(reg);
  _delay_us(5 * I2C_DELAY);
  tx(value);
  _delay_us(5 * I2C_DELAY);
  stop();
  sei();
}
// MMA8653FC Functions
void testI2C_read() {
  uint8_t whoAmI = readRegister(MMA8653FC_WHO_AM_I);
  if (whoAmI == 0x5A) {
    showHook();
  }
  else {
    showCross();
    _delay_ms(SLEEP_THRESHOLD);
    goToSleep();
  }
}
void MMA8653FC_init() {
  writeRegister(MMA8653FC_XYZ_DATA_CFG, 0x00); // 2g range
  writeRegister(MMA8653FC_CTRL_REG1, 0x01); // Active and fast read mode
}
void MMA8653FC_deInit() {
  writeRegister(MMA8653FC_CTRL_REG1, 0x00); // Standby mode
}
void getAcceleration(int16_t* x, int16_t* y, int16_t* z) {
  int16_t x_msb = 0, x_lsb = 0, y_msb = 0, y_lsb = 0, z_msb = 0, z_lsb = 0;
  x_msb = readRegister(MMA8653FC_OUT_X_MSB);
  x_lsb = readRegister(MMA8653FC_OUT_X_LSB);
  y_msb = readRegister(MMA8653FC_OUT_Y_MSB);
  y_lsb = readRegister(MMA8653FC_OUT_Y_LSB);
  z_msb = readRegister(MMA8653FC_OUT_Z_MSB);
  z_lsb = readRegister(MMA8653FC_OUT_Z_LSB);
  *x = x_msb << 8 | x_lsb;
  *y = y_msb << 8 | y_lsb;
  *z = z_msb << 8 | z_lsb;
}
// Data processing and display
void dynamicDelay(uint16_t ms) {
  while (0 < ms)
  {
    _delay_ms(1);
    ms--;
  }
}
float getAngle(float axis, float reference) {
  return (atan(axis / reference) * 4068) / 71; // (radians * 4068) / 71
}
void getRollNick(float* roll, float* nick){
  int16_t x, y, z;
  // First we get raw data from the accelerometer
  getAcceleration(&x, &y, &z);
  // Then we substract the offset from the x and y axis, 
  // to get better relative measurements (full calibration is not implemented)
  x = (x - x_offset);
  y = (y - y_offset);
  if (z == 0)z = 1; // Avoid division by zero
  z = -abs(z);      // Sensor is mounted upside down -> abs cause of tilt > 90°
  // The next step is to calculate the angle of the roll and nick
  // TODO: better calculation with sqrt(y * y + z * z) and sqrt(x * x + z * z)
  *roll = getAngle((float)x, (float)z_offset); // Not exact but sufficient, precise: sqrt(y * y + z * z) instead of z_offset
  *nick = getAngle((float)y, (float)z_offset);
}
int16_t getGradient(int16_t baseValue){
  static int16_t prev_baseValue;
  int16_t gradient = 0;

  if(!prev_baseValue){
    prev_baseValue = baseValue;
  }
  else{
    gradient = baseValue - prev_baseValue;
    prev_baseValue = baseValue;
  }
  return gradient;
}
bool motionDetected(uint8_t threshold) {
  float roll, nick;
  // First we get raw data from the accelerometer
  getRollNick(&roll, &nick);

  nick = getGradient(nick);
  roll = getGradient(roll);

  if (nick > threshold || roll > threshold) {
    return true;
  }
  else {
    return false;
  }
}
void spritLevel() {
  float roll, nick;

  getRollNick(&roll, &nick);
  // Now we display the anles with the LED'S
  allLedOff();
  // check if the device is balanced
  if (abs(nick) < ANGLETHRESHOLD && abs(roll) < ANGLETHRESHOLD) {
    PORTA |= (1 << D4);
  }
  // If it's not balanced, we check if we nick or gier
  else {
    if (abs(roll) > abs(nick))
    {
      if (roll < 0) // LED1, LED3, LED6
      {
        if (abs(nick) < ANGLETHRESHOLD)
        {
          PORTA |= (1 << D1);
          PORTA |= (1 << D3);
          PORTA |= (1 << D6);
        }
        else
        {
          if (nick < 0)
            PORTA |= (1 << D1);
          else
            PORTA |= (1 << D6);
        }
      }
      else // lED2, LED5, LED7
      {
        if (abs(nick) < ANGLETHRESHOLD)
        {
          PORTA |= (1 << D2);
          PORTA |= (1 << D5);
          PORTB |= (1 << D7);
        }
        else
        {
          if (nick < 0)
            PORTA |= (1 << D2);
          else
            PORTB |= (1 << D7);
        }
      }
    }
    else
    {
      if (nick < 0) // LED1, LED2
      {
        if (abs(roll) < ANGLETHRESHOLD)
        {
          PORTA |= (1 << D1);
          PORTA |= (1 << D2);
        }
        else
        {
          if (roll < 0)
            PORTA |= (1 << D1);
          else
            PORTA |= (1 << D2);
        }
      }
      else // LED6, LED7
      {
        if (abs(roll) < ANGLETHRESHOLD)
        {
          PORTA |= (1 << D6);
          PORTB |= (1 << D7);
        }
        else
        {
          if (roll < 0)
            PORTA |= (1 << D6);
          else
            PORTB |= 1 << D7;
        }
      }
    }
  }
}
void dice() {
  uint16_t timeSteps = DICE_TIME_STEPS;
  uint8_t randomeNumber = 0;
  // Set the randome seed
  srand(counter);
  // First dice relatively fast
  for (uint8_t i = 0; i < DICE_STEPS_FIRST_ROUND; i++) {
    dynamicDelay(timeSteps);
    randomeNumber = (rand() % 6) + 1;
    showNumber(randomeNumber);
  }
  // Then dice slower on every loop iteration
  for (uint8_t i = 0; i < DICE_STEPS_SECOND_ROUND; i++) {
    dynamicDelay(timeSteps + DICE_TIME_STEPS_INCREASE);
    randomeNumber = (rand() % 6) + 1;
    showNumber(randomeNumber);
    timeSteps += DICE_TIME_STEPS;
  }
}
// Calibration sequence after wakeup
void calibrate() {
  int16_t x, y, z;
  int32_t x_increment = 0, y_increment = 0, z_increment = 0;
  // Check if all LED's are working
  allLedOn();
  _delay_ms(CALIBRATION_STEP_DELAY);
  // Check if the accelerometer is working
  showNumber(1);
  _delay_ms(CALIBRATION_STEP_DELAY);
  testI2C_read();
  _delay_ms(CALIBRATION_STEP_DELAY);
  showNumber(2);
  _delay_ms(CALIBRATION_STEP_DELAY);
  // Get the sensor offset x times
  for (uint8_t i = 0; i < OFFSET_CALIBRATION_STEPS; i++) {
    getAcceleration(&x, &y, &z);
    x_increment += x;
    y_increment += y;
    z_increment += z;
    _delay_ms(OFFSET_CALIBRATION_STEP_DELAY);
  }
  // Form the mean value
  x_offset = x_increment / OFFSET_CALIBRATION_STEPS;
  y_offset = y_increment / OFFSET_CALIBRATION_STEPS;
  z_offset = z_increment / OFFSET_CALIBRATION_STEPS;
  // Indicate that the calibration is done
  showHook();
  _delay_ms(CALIBRATION_STEP_DELAY);
  button_pressed++; // causing jump in the loop
}
// Sleep routine
void goToSleep() {
  set_sleep_mode(SLEEP_MODE_PWR_DOWN);
  MMA8653FC_deInit();
  deInit();
  _delay_ms(10);
  sleep_mode();
}

// ---------------------------------------------------------------- //
// -- Main Function ----------------------------------------------- //
// ---------------------------------------------------------------- //
int main()
{
  // Main loop.
  init();
  MMA8653FC_init();
  // When battery is put in for the first time, buttton is not pressed.
  // But we want to do the calibration sequence, so we set button_pressed to "1".
  if (button_pressed == 0) button_pressed = 1;
  while (1)
  {
    // Right after wakeup, the button is pressed once, so we do the calibration sequence.
    if (button_pressed == 1) {
      calibrate();
    }
    else {
      // If button is pressed even times (2, 4, 6, ...), we do "dice" mode.
      if (button_pressed % 2) {
        if (motionDetected(ANGLE_GRADIENT_THRESHOLD) == true) {
          dice();
          _delay_ms(10);
        }
      }
      else {
        // If button pressed odd times, we are in "sprit level" mode
        spritLevel();
      }
      // Check if the device is in motion to prevent sleep
      if (motionDetected(ANGLE_GRADIENT_THRESHOLD) == true) {
        counter = 0;
      }
      // If button is pressed odd times, we do spirit level mode.
      // Go to sleep if inactivity
      if (counter >= SLEEP_THRESHOLD) {
        goToSleep();
      }
    }
  }
}
// --------------------------------------------------------------- //
// -- Interrupts ------------------------------------------------- //
// --------------------------------------------------------------- //
ISR(INT0_vect) // button interrupt
{
  uint16_t force_sleep_counter = 0;
  cli(); // disable interrupts, to prevent double counting
  allLedOff();
  button_pressed++;
  while (!(PINB & (1 << BUTTON))) {
    force_sleep_counter++; // increase force sleep counter if button is still pressed
    showNumber(force_sleep_counter / FORCE_SLEEP_STEPTIME);
    _delay_ms(1);
  }
  if (force_sleep_counter >= FORCE_SLEEP_TIME) {
    goToSleep();
    return;
  }
  else {
    _delay_ms(10); // wait for debounce
  }
  counter = 0;     // reset counter, cause pressing button is external activity from user
  sei();           // enable interrupts again
  main();          // reload the main application (causing a mode change from dice to level and vice versa)
}
ISR(TIM0_COMPA_vect) // Sleep timer overflow.
{
  counter++;
}

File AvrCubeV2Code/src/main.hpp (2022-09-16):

/**
 * @file main.hpp
 * @author Fabian Franz fabian.franz0596@gmail.com
 * @brief Includes, defines and function prototypes for the "Cube Project".
 * @version 09.22
 * @date 2022-09-14
 * 
 * @copyright Copyright (c) 2022
 * 
 * \code
  ______          _    _                 _                  
 |  ____|   /\   | |  | |               | |                 
 | |__     /  \  | |__| |  ______       | | ___ _ __   __ _ 
 |  __|   / /\ \ |  __  | |______|  _   | |/ _ \ '_ \ / _` |
 | |____ / ____ \| |  | |          | |__| |  __/ | | | (_| |
 |______/_/    \_\_|  |_|           \____/ \___|_| |_|\__,_|
                                                                                                           
 * \endcode
 */

#ifndef MAIN_HPP
#define MAIN_HPP

// ---------------------------------------------------------------- //
// -- Includes ---------------------------------------------------- //
// ---------------------------------------------------------------- //
#include <math.h>
#include <stdlib.h>
#include <avr/io.h>
#include <avr/sleep.h>
#include <util/delay.h>
#include <avr/interrupt.h>

// ---------------------------------------------------------------- //
// -- Defines ----------------------------------------------------- //
// ---------------------------------------------------------------- //
#define F_CPU 8000000
#define __DELAY_BACKWARD_COMPATIBLE__
// Defines for the button pin
#define BUTTON PB2
// Defines for the connected LEDs
#define D1 PA0
#define D2 PA1
#define D3 PA2
#define D4 PA3
#define D5 PA5
#define D6 PA7
#define D7 PB1
// Defines for the SPI interface.
#define SCK PA4
#define MISO PA5
#define MOSI PA6
// Defines for the I2C interface (no hardware interface).
#define SCL PA4
#define SDA PA6
// Defines for unconnected pins
#define UNCONNECTED PB0

// General defines
#define OUTPUT 0
#define INPUT 1
#define ENABLE true
#define DISABLE false
#define ON true
#define OFF false

// Defines for control flow
#define SLEEP_THRESHOLD 60000                 // Millieconds until the device go to sleep if no action occurs
#define ANGLE_GRADIENT_THRESHOLD 25  // The threshold for the absolute motion value in LSB registers
#define DICE_STEPS_FIRST_ROUND 5    // The number of steps the dice has to roll
#define DICE_STEPS_SECOND_ROUND 5   // The number of steps the dice has to roll
#define DICE_TIME_STEPS 100         // The time step between dice rolls in ms
#define DICE_TIME_STEPS_INCREASE 10 // The time step increase between dice rolls in ms in secon round
#define ANGLETHRESHOLD 1            // The threshold for the angle in degrees
#define CALIBRATION_STEP_DELAY 500  // The delay between calibration steps in ms
#define OFFSET_CALIBRATION_STEPS 10      // The number of calibration steps
#define OFFSET_CALIBRATION_STEP_DELAY 10 // The delay between offset calibration steps in ms
#define FORCE_SLEEP_STEPTIME 500         // The delay until new number
#define FORCE_SLEEP_TIME 6 * FORCE_SLEEP_STEPTIME // When button is hold this amout of milliseconds the device will go to sleep
#define MOTION_MEASURING_REPETITIONS 5 // The number of repetitions for the motion measuring

// Defines for I2C
#define I2C_DELAY 10 // 10 us -> 100 kHz
#define SDA_ON (PORTA |= (1 << SDA))
#define SDA_OFF (PORTA &= ~(1 << SDA))
#define SCL_READ (PINA & (1 << SCL))
#define SDA_READ (PINA & (1 << SDA))
// Defines for Acceleration Sensor
#define MMA8653FC_ADD 0x1D
#define MMA8653FC_ADDR_READ 0x3B
#define MMA8653FC_ADDR_WRITE 0x3A
// Defines for Acceleration Sensor Registers
#define MMA8653FC_WHO_AM_I 0x0D
#define MMA8653FC_XYZ_DATA_CFG 0x0E
#define MMA8653FC_CTRL_REG1 0x2A
#define MMA8653FC_SYSMOD 0x0B    // System Mode, to control STANDBY, WAKE and SLEEP
#define MMA8653FC_OUT_X_MSB 0x01 // Most significant byte of X-axis acceleration data
#define MMA8653FC_OUT_X_LSB 0x02 // Least significant byte of X-axis acceleration data
#define MMA8653FC_OUT_Y_MSB 0x03 // Most significant byte of Y-axis acceleration data
#define MMA8653FC_OUT_Y_LSB 0x04 // Least significant byte of Y-axis acceleration data
#define MMA8653FC_OUT_Z_MSB 0x05 // Most significant byte of Z-axis acceleration data
#define MMA8653FC_OUT_Z_LSB 0x06 // Least significant byte of Z-axis acceleration data

// ---------------------------------------------------------------- //
// -- Function Prototypes ----------------------------------------- //
// ---------------------------------------------------------------- //
/**
 * @brief Set the LED Pins eigther "INPUT" or "OUTPUT"
 * 
 * @param mode OUTPUT = 0 or INPUT = 1
 */
void setLedPins(uint8_t mode);

/**
 * @brief Set the SDA pin eighter "ON" or "OFF".
 * 
 * @param mode "ON" (input pullup) or "OFF" (output low)
 */
void setSDA(bool mode);

/**
 * @brief Set the SCL pin eighter "ON" or "OFF".
 * 
 * @param mode "ON" (input pullup) or "OFF" (output low)
 */
void setSCL(bool mode);

/**
 * @brief Initialises all the AVR hardware E.g. ports, interrupts, timers, etc.
 */
void init();
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

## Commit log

2022-09-15 Exported Gerber, Added Comments, Added Doxygen
    [avrCubeRev2-B_Cu.gbr, avrCubeRev2-B_Mask.gbr, avrCubeRev2-B_Paste.gbr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]
2022-11-26 FINAL version
    [avrCubeRev2-B_Cu.gbr, avrCubeRev2-B_Mask.gbr, avrCubeRev2-B_Paste.gbr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]
2023-02-08 REMOVED latex sources
    [avrCubeRev2.kicad_pcb]
2026-09-16 Remove build output, KiCad backups and duplicate archives from the tree
    Drop the stale machine-specific .vscode build config, generated Doxygen
    HTML/LaTeX, KiCad auto-backups and -bak files, and the zip/7z copies of
    directories that are already checked in unpacked. Make the Doxyfile and
    flash command use relative paths. Replace .gitignore so these stay out.
